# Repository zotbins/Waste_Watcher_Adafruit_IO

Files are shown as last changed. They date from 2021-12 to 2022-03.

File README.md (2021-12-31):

# Waste Watcher Adafruit IO
<!-- ALL-CONTRIBUTORS-BADGE:START - Do not remove or modify this section -->

<!-- ALL-CONTRIBUTORS-BADGE:END -->

Waste Watcher is an IoT based sensor module to help keep track of waste data metrics with real-time bin fullness data and waste images. This is intended to help quantify and promote actionable solutions to reduce waste. This project is a continuation of [waste_watcher](https://github.com/zotbins/waste_watcher).

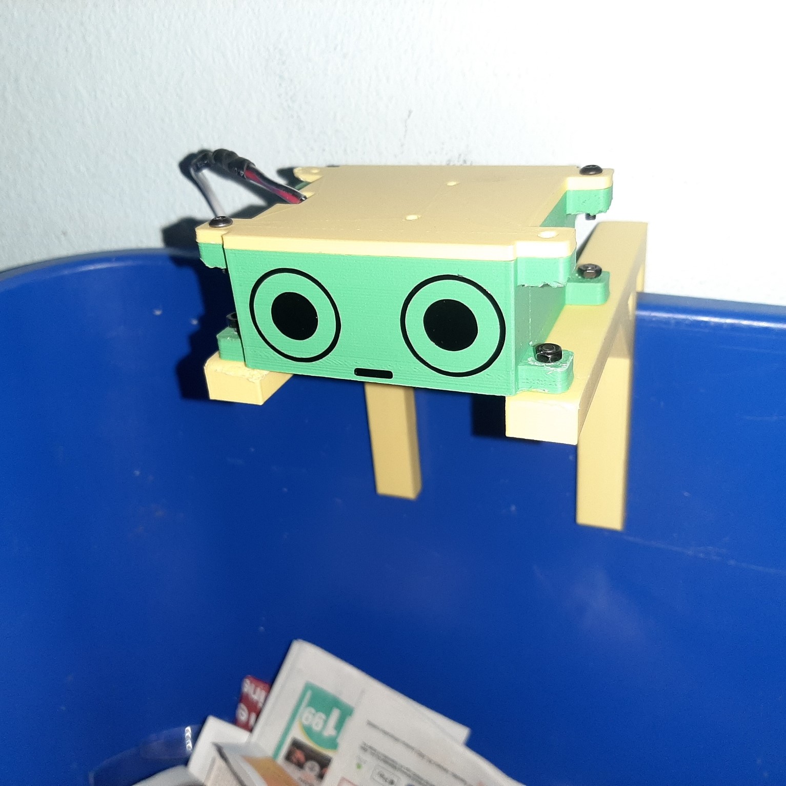
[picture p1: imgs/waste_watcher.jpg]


## Features

- 🗑 Collect waste bin fullness telemetry
- 📷 Capture image of inside the waste bin
- 🔧 Fully customizable (adjust data collection rate, tweak case design for your needs, change camera settings, etc.)

## Why?  ¯\\_(ツ)_/¯
Simply put, we generate way too much waste here in the United States 🤧. According to the [EPA](https://www.epa.gov/sites/default/files/2019-03/documents/infographic_full-060513_v4.pdf), 267.8 million tons of trash were generated. And even though the US represents 4% of the global population we generate 12% of global municipal solid waste, right behind India and China ( [Verisk Maplecroft, 2019](https://www.maplecroft.com/insights/analysis/us-tops-list-of-countries-fuelling-the-mounting-waste-crisis/)). The trash itself also presents other harmful environmental impacts. US landfills are the 3rd largest source of human-related methane emissions ([EPA](https://www.epa.gov/lmop/basic-information-about-landfill-gas)). Waste also affects 43% of marine mammals ([EPA 2017](https://19january2017snapshot.epa.gov/trash-free-waters/impacts-mismanaged-trash_.html)).

Waste monitoring systems already exist in commercial settings, ZotBins expands waste monitoring to the individual and community level. Some of these existing systems include [Bigbelly](https://bigbelly.com/), [Compology](https://compology.com/), and [Enevo](https://enevo.com/index.html). ZotBins is completely opensource. Built for people, by people.

## Adafruit IO

This repo, in particular, uses [Adafruit IO](https://io.adafruit.com/), an off-the-shelf IoT platform. For now, Adafruit IO is a great addition to this project and helps in the following ways:
- 🤗 Helps makes the project more user-friendly (no need to setup your own server, ready to use APIs, Dashboard feature)
- 🆓 Free to use F O R E V E R ╰(*°▽°*)╯ (according to their [website](https://io.adafruit.com/))
- 🤝 Great community on Discord willing to help people out
- 🔒 Data is never [sold](https://www.adafruit.com/iotbor/)

## Getting Started

Follow the [Build Guide](./build_guide.md) 🛠.

## Actionable Ideas for Your Waste Data

Besides just collecting data, here are some ideas that you can implement. Again the goal of this project is to help quantify and promote actionable solutions to reduce waste.

- 🎯 Create a goal to reduce the rate at which you fill up a bin
- 💻 Use the Adafruit IO Integrations (Zapier, IFTTT)
    - Send a summary of weekly fullness rate
    - Send alerts when bin is full
- 🤖 Use machine learning to identify what items are thrown always
    - identify frequently thrown away items then try to reduce that waste (eg. plastic straws are identified frequently in the waste stream, so we can ban the straw or give sustainable alternatives)
    - identify which waste items are incorrectly thrown away

## Contributors ✨

Thanks goes to these wonderful people ([emoji key](https://allcontributors.org/docs/en/emoji-key)):
<!-- ALL-CONTRIBUTORS-LIST:START - Do not remove or modify this section -->
<!-- prettier-ignore-start -->
<!-- markdownlint-disable -->
<table>
  <tr>
    <td align="center"><a href="http://www.ics.uci.edu/~primal/"><br /><sub><b>Primal Pappachan</b></sub></a><br /><a href="https://github.com/zotbins/Waste_Watcher_Adafruit_IO/pulls?q=is%3Apr+reviewed-by%3Aprimalpop" title="Reviewed Pull Requests">👀</a></td>
    <td align="center"><a href="https://github.com/patrickanguyen"><br /><sub><b>Patrick Nguyen</b></sub></a><br /><a href="https://github.com/zotbins/Waste_Watcher_Adafruit_IO/commits?author=patrickanguyen" title="Code">💻</a> <a href="https://github.com/zotbins/Waste_Watcher_Adafruit_IO/pulls?q=is%3Apr+reviewed-by%3Apatrickanguyen" title="Reviewed Pull Requests">👀</a></td>
  </tr>
</table>

<!-- markdownlint-restore -->
<!-- prettier-ignore-end -->

This project follows the [all-contributors](https://github.com/all-contributors/all-contributors) specification. Contributions of any kind welcome!

## Credits/Acknowledgements

1. [ESP32Cam-MQTT by abish7643](https://github.com/abish7643/ESP32Cam-MQTT) - Great reference in how to send images through MQTT
2. [ESP32-CAM Projects by Random Nerd Tutorials](https://randomnerdtutorials.com/projects-esp32-cam/) - Quality background information on getting started with the ESP32-CAM

## How this Project Started

This project started at UCI in 2017 with a group of 4 undergraduates for a hackathon hosted by UCI TIPPERS. The aim of the project was to help create a tool to help with UCI's zero waste initiatives. Since then, the project is being shared to the open-source community through ZBCE and the ZotBins UCI undergraduate team continues with new members every year.

## Other Links

1. [License](LICENSE)
2. [Contributing](CONTRIBUTING.md)
3. [Code of Conduct](CODE_OF_CONDUCT.md)

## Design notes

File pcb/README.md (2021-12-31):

## Waste Watcher PCB

The original KiCad project files are included so that you can modify it. Extract the project files from the `.zip` file and view it with [KiCad](https://www.kicad.org/).

You can also purchase the PCB from [OshPark](https://oshpark.com/) using this [link](https://oshpark.com/shared_projects/9fNFnSUL).

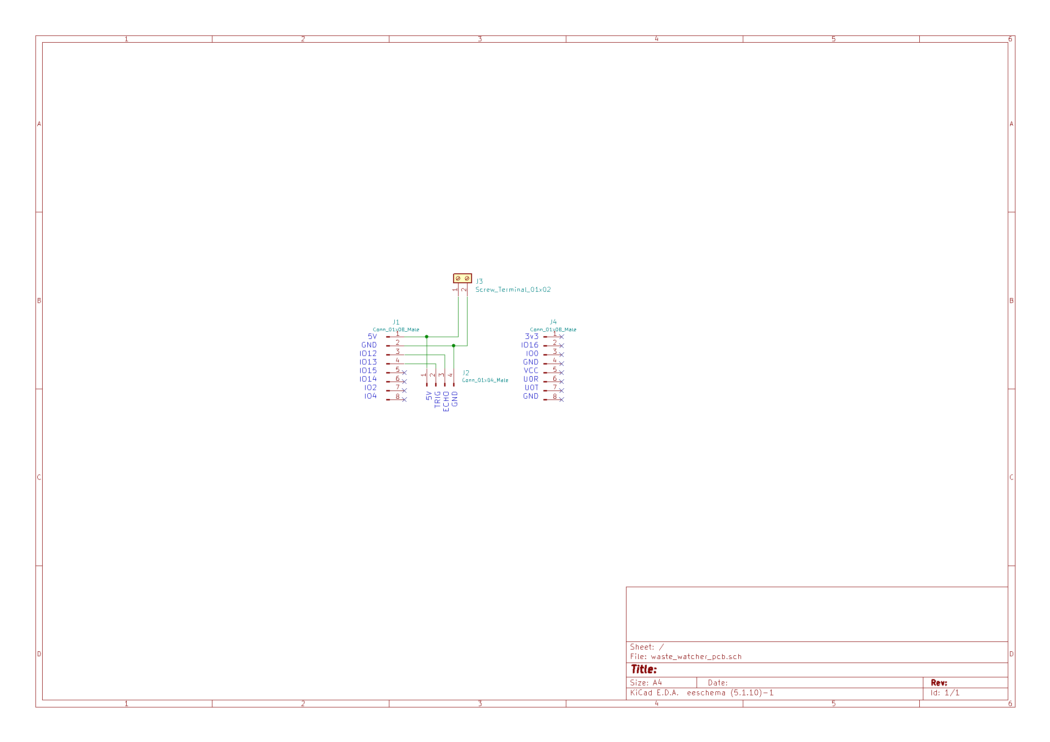
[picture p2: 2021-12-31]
pcb/schematic.png

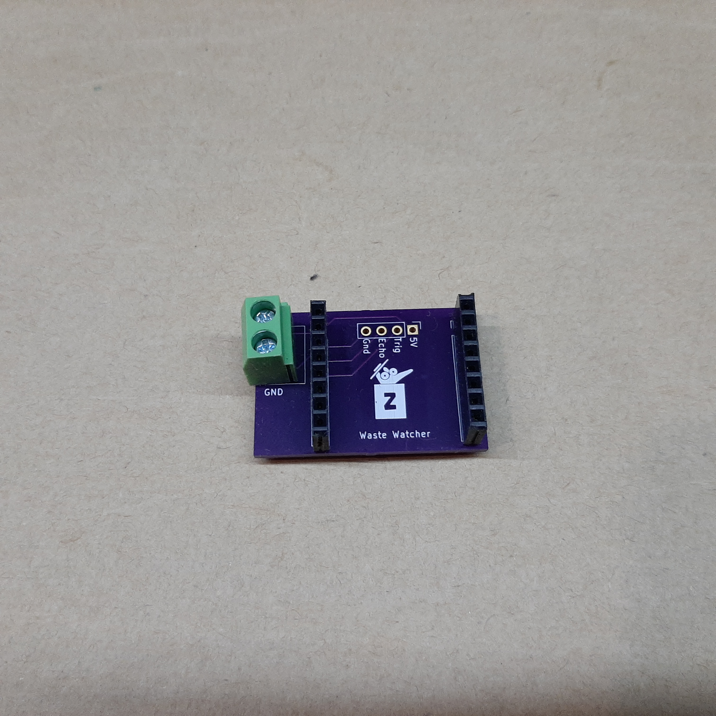
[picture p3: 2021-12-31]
imgs/zotbins_pcb.jpg

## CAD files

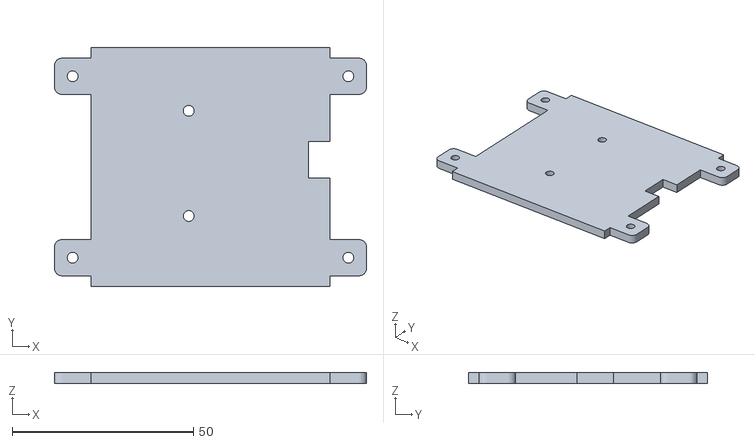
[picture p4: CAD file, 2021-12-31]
stl/sensor_mod_top_assembly.stl
86.0 x 66.0 x 3.00

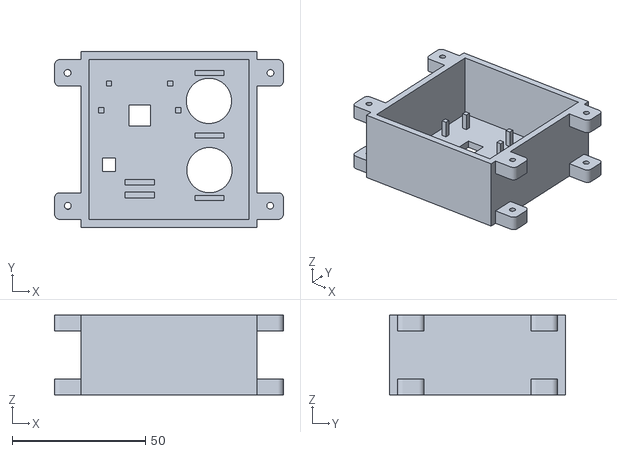
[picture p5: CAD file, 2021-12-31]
stl/sensor_mod_bottom_assembly.stl
86.0 x 66.0 x 30.0

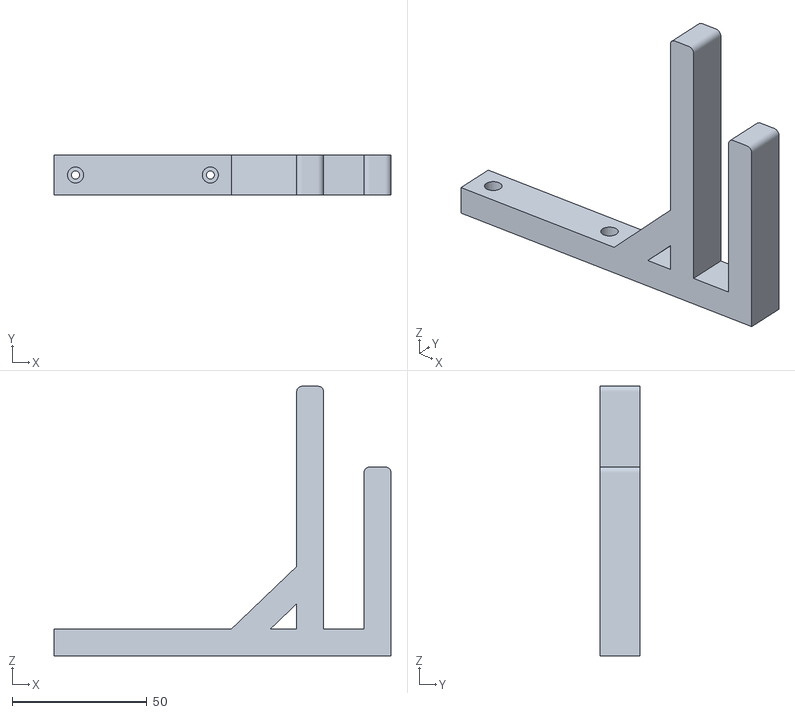
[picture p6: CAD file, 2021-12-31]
stl/sensor_mod_handle.stl
125.0 x 15.0 x 100.0

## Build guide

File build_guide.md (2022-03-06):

# Waste Watcher Build Guide

The intent of this guide is to be clear and provide comprehensive instruction to help you build and setup your waste watcher. If you would like to suggest any improvements feel free to submit an issue or refer to the [Contributing](CONTRIBUTING.md) Guide.

## Materials
- [ ] PLA Filament
- [ ] ESP32-CAM
- [ ] HC-SR04
- [ ] Solid Core Wire
- [ ] Waste Watcher PCB
- [ ] 6 of 12mm M3 Screws
- [ ] 6 M3 nuts
- [ ] 1 of the 2 Pin Screw Terminal
- [ ] 2 of the 1 x 8 Female header pins
- [ ] Spare USB cable
- [ ] Heat Shrink

## Equipment Needed
- [ ] 3D printer (or 3D Printing Service)
- [ ] Soldering Iron
- [ ] Helpings Hands for Soldering
- [ ] Wire Stripper
- [ ] Computer
- [ ] FTDI Adapter and 4 Female to Female Adapter
- [ ] Jumper Cap

## 1 - 3D Print the Case
If you don't have a 3D printer, you can search up some local 3D printing services in your favorite search browser.

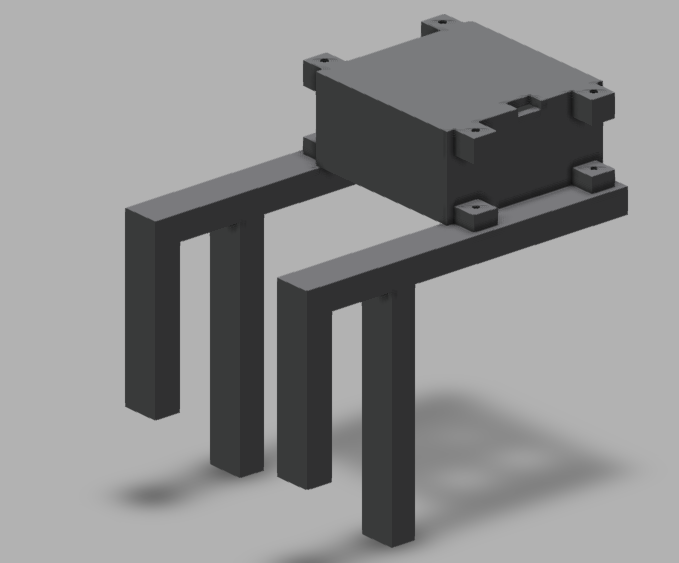
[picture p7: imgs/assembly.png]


1. Before starting make sure that your bin is compatible with the case. If not, you may need to modify or create different handles. (please share them if you do! 🙂)
2. Refer to the settings below and print the following:
    1. 2 of the `sensor_mod_handle.stl`
    2. 1 of the `sensor_mod_bottom_assembly.stl`
    3. 1 of the `sensor_mod_top_assembly.stl`
3. Screw on the handles
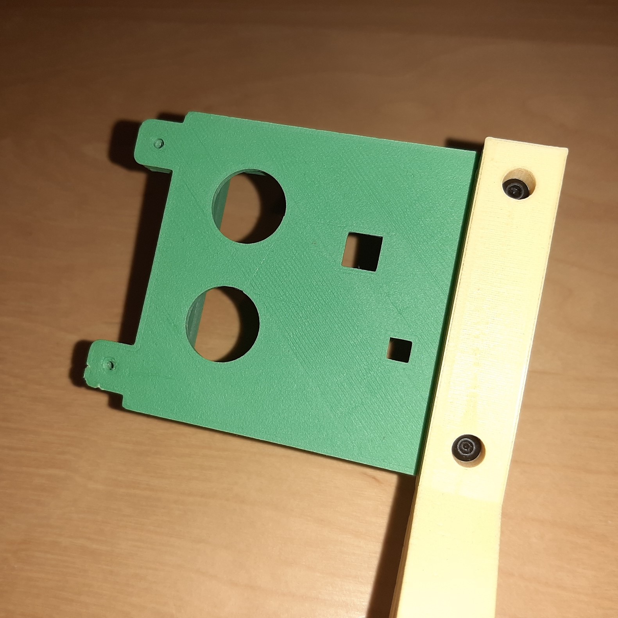
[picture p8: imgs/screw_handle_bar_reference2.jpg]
    

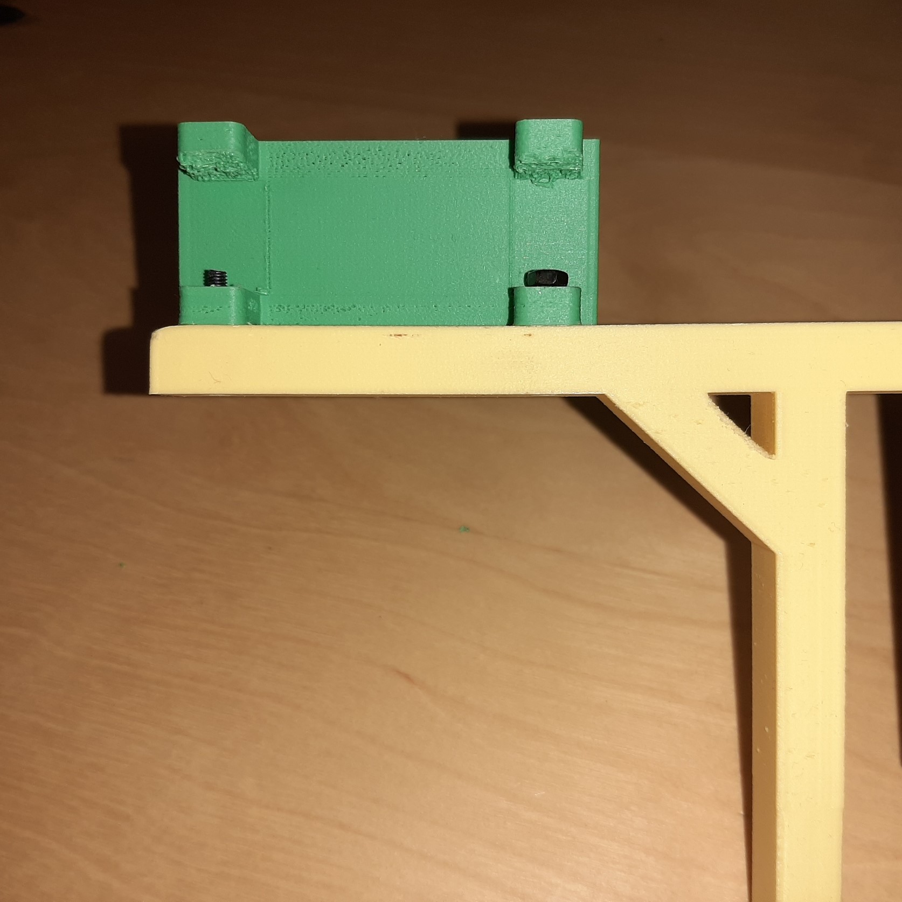
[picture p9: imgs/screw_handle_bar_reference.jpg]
    

| Setting | Value |
| ---| ----- |
| Layer height (mm) | 0.1 |
| Shell thickness (mm) | 0.8 |
| Bottom/Top thickness (mm) | 1.5 |
| Fill Density (%) | 30 |
| Print speed (mm/s) | 50 |
| Support type | Everywhere |
| Platform adhesion type | None |

## 2 - Circuit
You can purchase the PCB from [OshPark](https://oshpark.com/) using this [link](https://oshpark.com/shared_projects/9fNFnSUL). Or if you prefer, you can refer to the schematic/KiCad files in the `pcb` folder and create your circuit on a prototyping board.

1. Let's recycle! ♻ Take your spare USB cable, cut the end, and expose the V+ (usually red) and GND (usually black)
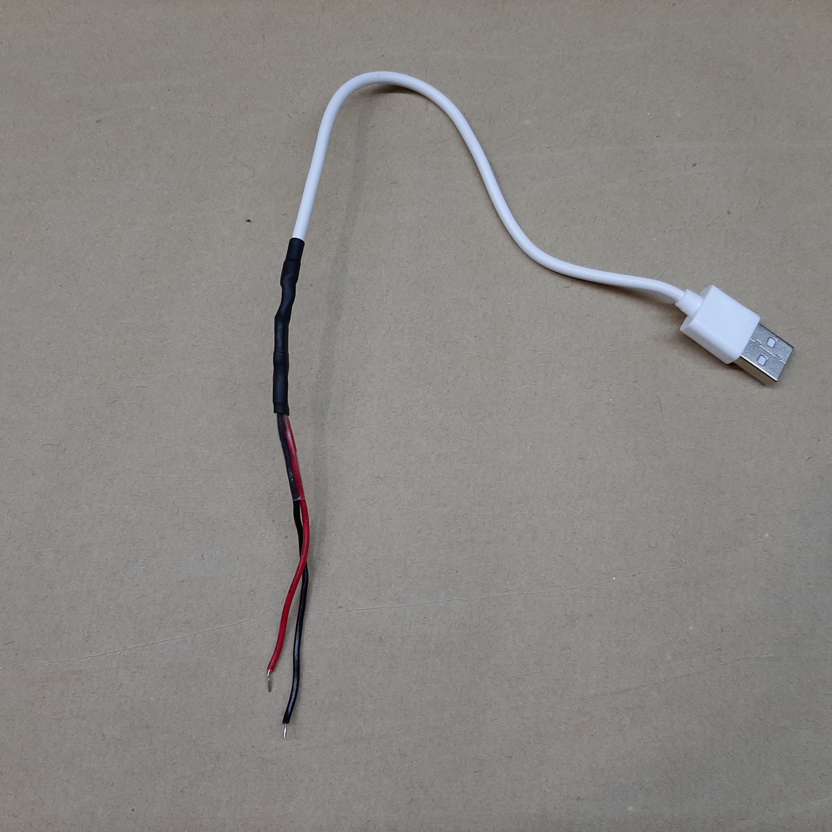
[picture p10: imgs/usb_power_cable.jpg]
    
2. Solder the components onto the PCB
    1. 2 Pin Screw Terminal
    2. 2 of the 1 x 8 Female header pins
3. Solder some wires onto the HC-SR04
4. Heat shrink to insulate
5. Solder the other ends of the wires into the PCB (use the labels to figure out which wire goes where)
3. Your circuit is good to go 👍
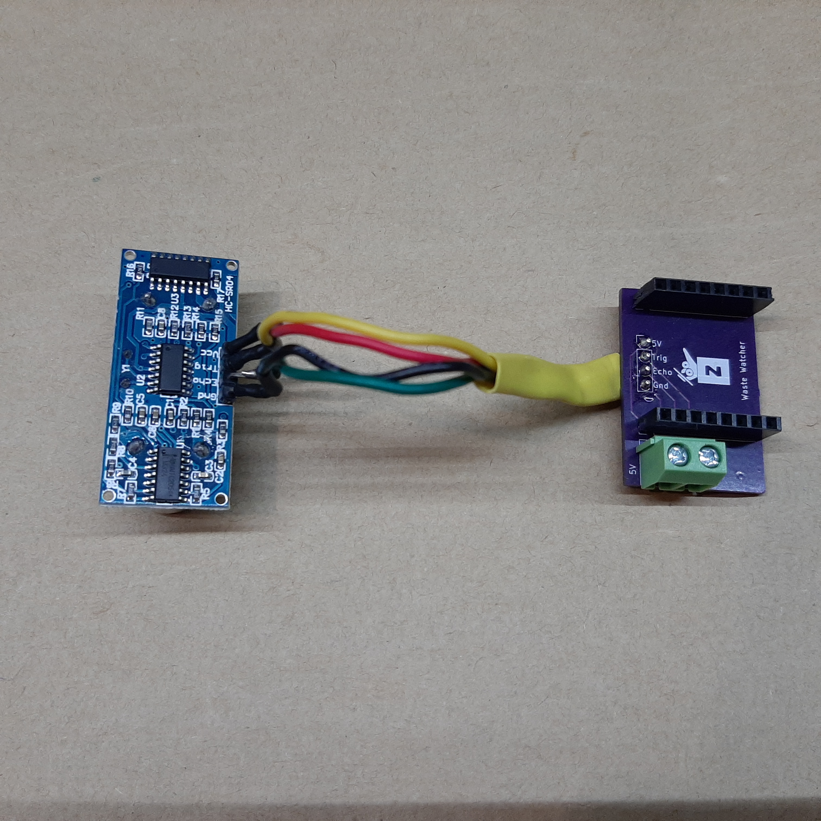
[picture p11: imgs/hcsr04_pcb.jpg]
    

## 3 - Adafruit IO Setup
1. Create an Adafruit IO account
2. Take note of your Adafruit IO Username and Key
    

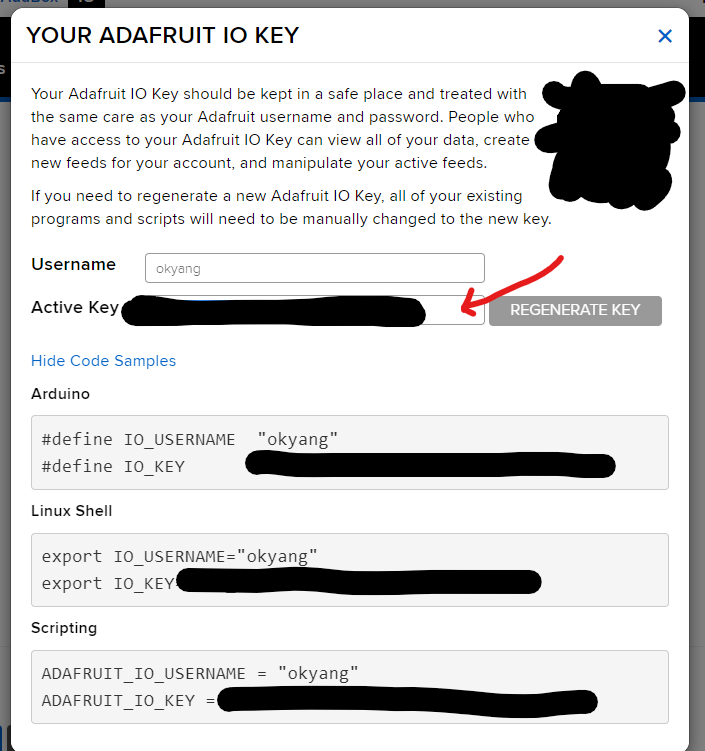
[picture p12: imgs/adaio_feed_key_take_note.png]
    
3. Create a Group
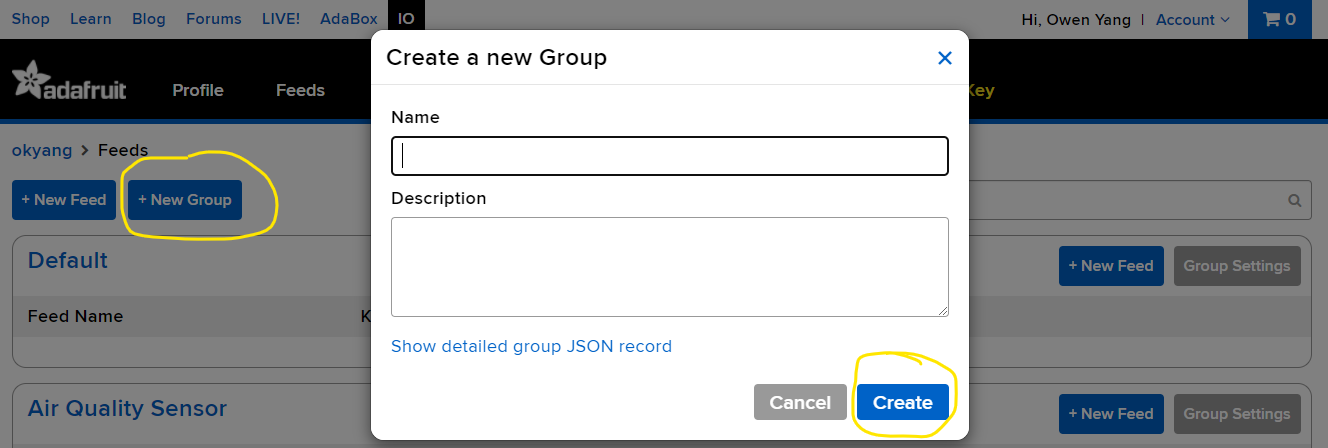
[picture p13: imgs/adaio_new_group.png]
    
4. Create your feeds for
    1. Bin Fullness
    2. Waste Image
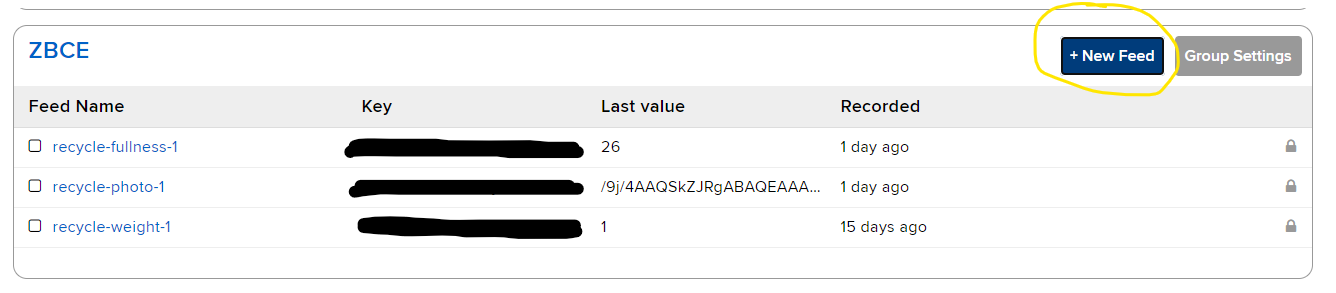
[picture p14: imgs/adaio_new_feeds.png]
    
5. Create a [Dashboard](https://learn.adafruit.com/adafruit-io-basics-dashboards) for your feeds. Here's an example that I made.
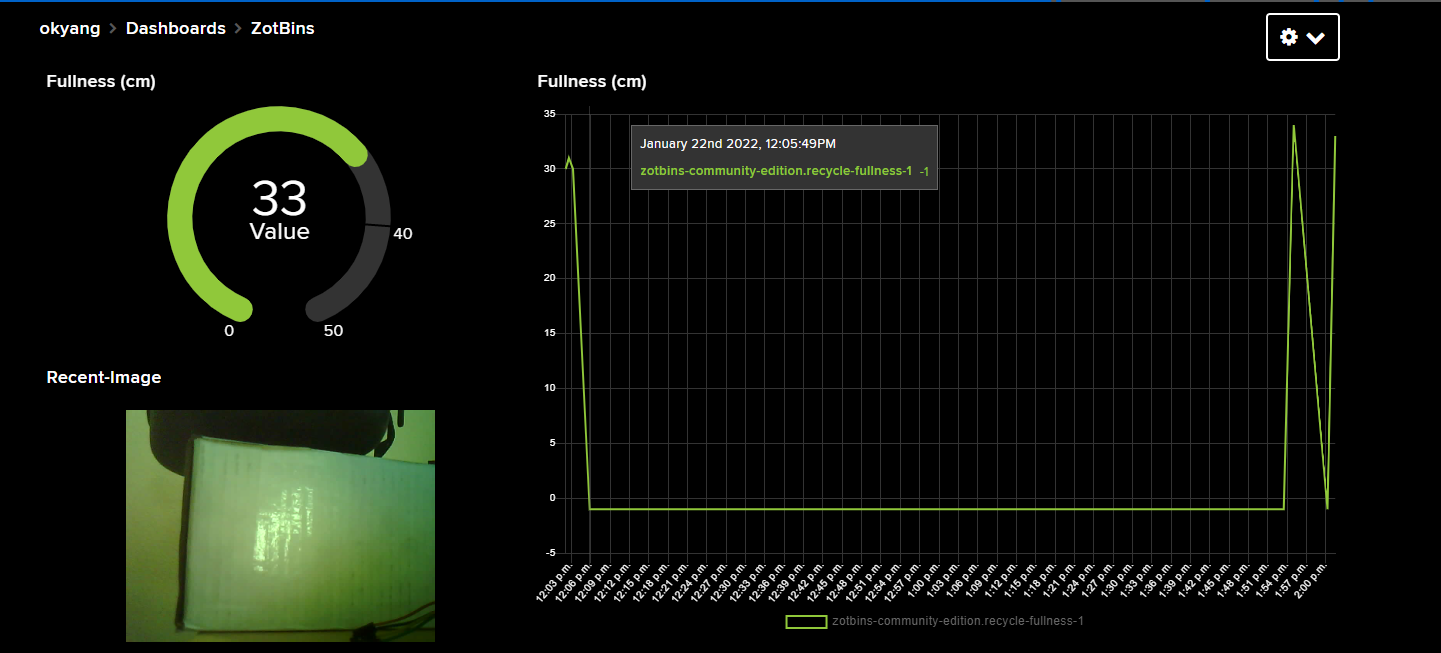
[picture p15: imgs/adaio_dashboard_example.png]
    

## 4 - Upload Code
Before getting started, make sure you satisfy these prerequisites below:
- [Visual Studio Code](https://code.visualstudio.com/)
- [Platform IO Extension Installed](https://platformio.org/install/ide?install=vscode)
- Repo Code Downloaded:
    - (Option 1) Download repo as zip and extract the contents
    - (Option 2) `git clone https://github.com/zotbins/Waste_Watcher_Adafruit_IO.git`

1. Open the subfolder `waste_watcher_adafruitIO` in Visual Studio Code
2. Create the file `config.h` in the `src` folder
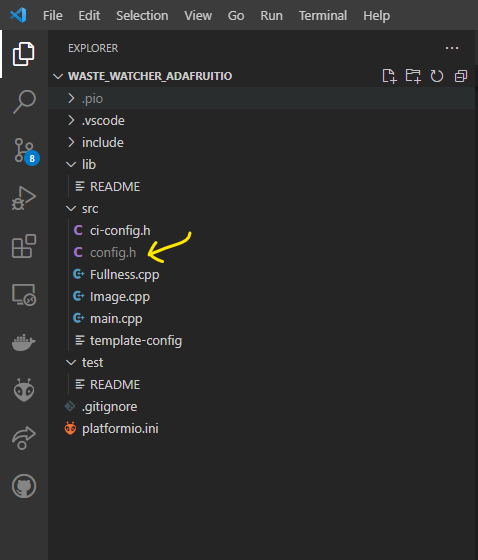
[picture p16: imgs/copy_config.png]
    
3. Copy the contents of `template-config` into your `config.h` file
4. Change the config settings for the following
    - `ssid` - your wifi name
    - `password` - this is your wifi password
    - `mqttClientID` - just a unique id. You can generate one with https://guidgenerator.com/
    - `mqttUsername` - this is your AdafruitIO username
    - `mqttPassword` - this your AdafruitIO key in the form of `<username>/feeds/<MQTT by Key>`. The key! Not your account password.
    - `mqttFullnessTopic` - the MQTT topic for the fullness feed you created
    - `mqttImageTopic` - the MQTT topic for the image feed you created
5. Measure the height of your bin and change `binHeight` value to reflect the height of your particular bin. That way the sensor module can calculate how full your bin is.
6. Change the other config settings as you see fit
7. Put a jumper cap on the ESP32-CAM `IO0` and `GND`
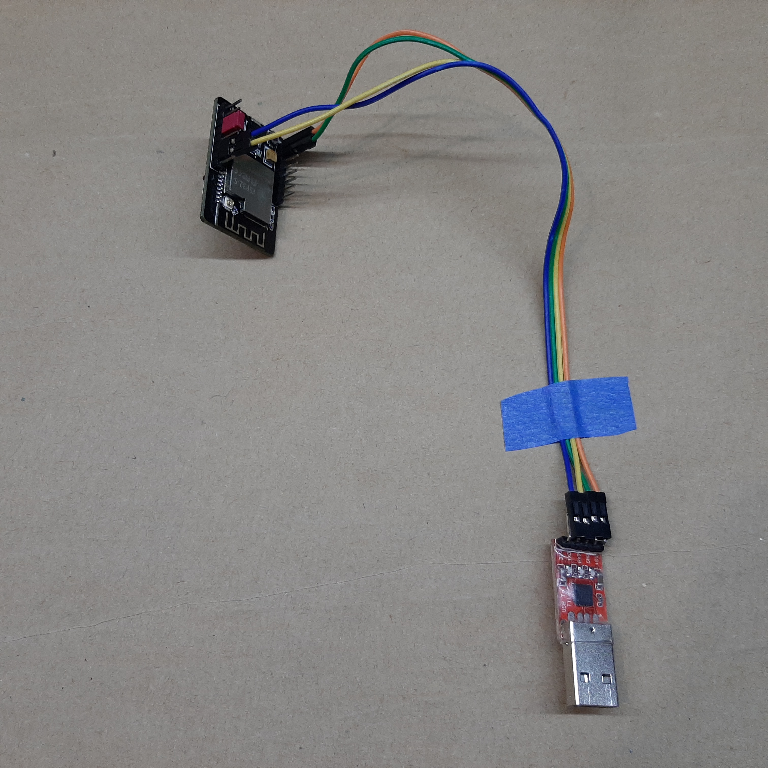
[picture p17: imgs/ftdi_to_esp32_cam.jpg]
    
8. Plug in your FTDI Adapter to the ESP32-CAM as shown
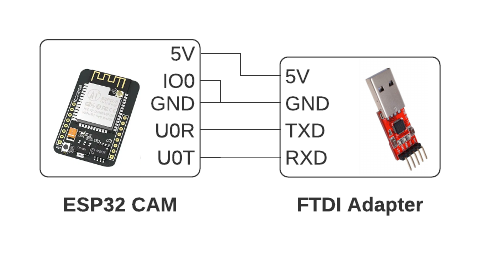
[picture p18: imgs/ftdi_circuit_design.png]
    
9. Plug in the FTDI Adapter into your computer
10. Click on the PlatformIO icon on the left side panel, then click **Upload and Monitor**. Wait for this to finish.
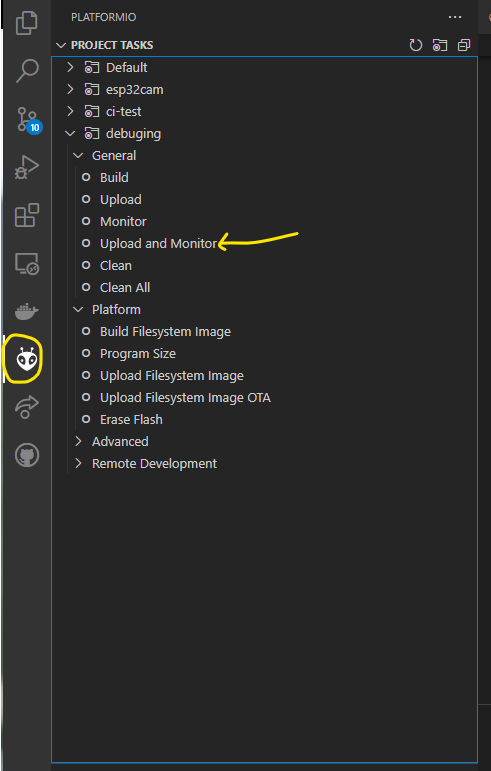
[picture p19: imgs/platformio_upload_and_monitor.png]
    
12. While leaving the ESP32-CAM plugged into the computer, Unplug the Jumper Cap and hit the reset button
13. Wait for data to be sent in Adafruit IO
    1. Fullness data should be sent as `-1` (because there is no HC-SR04 connected yet)
    2. Image should be sent

For troubleshooting the ESP32-CAM checkout this guide: [ESP32-CAM Troubleshooting Guide](https://randomnerdtutorials.com/esp32-cam-troubleshooting-guide/)

## 5 - Monitor Waste and Create Actionable Solutions

1. Plug your ESP32-CAM into your PCB
2. Screw in the USB power wires as shown (do not mix up power and ground!)
3. Put the HC-SR04 in and then the ESP32CAM in.
3. Screw on the lid with the USB cable coming out of the rectangular hole on top



Here are some actionable ideas from the README file:
> Besides just collecting data, here are some ideas that you can implement. Again the goal of this project is to help quantify and promote actionable solutions to reduce waste.
>
> - 🎯 Create a goal to reduce the rate at which you fill up a bin
> - 💻 Use the Adafruit IO Integrations (Zapier, IFTTT)
>    - Send a summary of weekly fullness rate
>    - Send alerts when bin is full
> - 🤖 Use machine learning to identify what items are thrown always
>    - identify frequently thrown away items then try to reduce that waste (eg. plastic straws are identified frequently in the waste stream, so we can ban the straw or give sustainable alternatives)
>    - identify which waste items are incorrectly thrown away

## Resources/Links
1. [Getting Started with VS Code and PlatformIO IDE for ESP32 and ESP8266 (Windows, Mac OS X, Linux Ubuntu)](https://randomnerdtutorials.com/vs-code-platformio-ide-esp32-esp8266-arduino/) - A guide to install Visual Studio Code and the PlatformIO Extension by Random Nerd Tutorials
2. [ESP32-CAM Video Streaming and Face Recognition with Arduino IDE](https://randomnerdtutorials.com/esp32-cam-video-streaming-face-recognition-arduino-ide/) - Great introduction to the ESP32-CAM by Random Nerd Tutorials
3. [ESP32-CAM Troubleshooting Guide](https://randomnerdtutorials.com/esp32-cam-troubleshooting-guide/) - common problems fixed for the ESP32-CAM by Random Nerd Tutorials

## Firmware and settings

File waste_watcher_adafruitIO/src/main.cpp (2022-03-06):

#include <Arduino.h>

#include "soc/soc.h"           // Disable brownout problems
#include "soc/rtc_cntl_reg.h"  // Disable brownout problems

#include <WiFi.h>
#include <PubSubClient.h>

#include <base64.h>
#include "Fullness.h"
#include "Image.h"

// create a `config.h` file based off of `template-config.h`
#ifdef CI
#include "ci-config.h"
#else
#include "config.h"
#endif

WiFiClient espClient;
PubSubClient client(espClient);

void reconnect();
void setup_wifi();

void setup_wifi()
{
  delay(10);
  // We start by connecting to a WiFi network
  #ifndef NDEBUG
  Serial.println();
  Serial.print("Connecting to ");
  Serial.println(ssid);
  #endif

  WiFi.begin(ssid, password);

  while (WiFi.status() != WL_CONNECTED)
  {
    delay(500);

    #ifndef NDEBUG
    Serial.print(".");
    #endif
  }

  #ifndef NDEBUG
  Serial.println("");
  Serial.println("WiFi connected");
  Serial.println("IP address: ");
  Serial.println(WiFi.localIP());
  #endif
}

void reconnect() {
  // Loop until we're reconnected
  while (!client.connected())
  {
    #ifndef NDEBUG
    Serial.print("Attempting MQTT connection...");
    #endif

    // Attempt to connect
    if (client.connect(mqttClientID, mqttUsername, mqttPassword))
    {
      #ifndef NDEBUG
      Serial.println("connected");
      #endif
    }
    else
    {
      #ifndef NDEBUG
      Serial.print("failed, rc=");
      Serial.print(client.state());
      Serial.println(" try again in 5 seconds");
      #endif

      // Wait 5 seconds before retrying
      delay(5000);
    }
  }
}

void setup() {
  #ifndef NDEBUG
  Serial.begin(115200);
  #endif

  // === deep sleep setup ===
  esp_sleep_enable_timer_wakeup(TIME_TO_SLEEP * uS_TO_S_FACTOR);

  // ---- set pins -----
  pinMode(ultrasonicTrigPin, OUTPUT);
  pinMode(ultrasonicEchoPin, INPUT);
  pinMode(FLASH, OUTPUT);

  // ---- telemetry variables ----
  int fullness;
  String base64Image; //base-64 encoded string to represent a JPG image

  // ---- Read Fullness ----
  fullness = calculateFullness(ultrasonicTrigPin, ultrasonicEchoPin, binHeight, 0, binHeight, retries);

  // ---- Get Picture ----
  configInitCamera();
  base64Image = takePhoto(flashOn);

  #ifndef NDEBUG
  Serial.print("\nFullness: ");
  Serial.println(fullness);
  Serial.println("Image captured.");
  if (base64Image.length() > 102400) {
    Serial.println("Image size too big");
    return;
  }
  #endif

  // ---- MQTT Setup -----
  setup_wifi();
  client.setServer(mqttServer, 1883);
  if (!client.connected()) {
    reconnect();
  }
  client.loop();

  // ----- Send Fullness Telemetry w/ 5 retry chances-----
  char payload[32] = {0};
  snprintf(payload, sizeof(payload), "%d", fullness);

  bool fullnessSent;
  for (int i=0; i<5; i++) {
    fullnessSent = client.publish(mqttFullnessTopic, payload);
    if (fullnessSent) break;
    delay(1000);
  }

  // --- Send Picture to MQTT w/ 5 retry chances ---
  bool imageSent;
  for (int i=0; i<6; i++) {
    imageSent = client.publish(mqttImageTopic, base64Image.c_str());
    if (imageSent) break;
    delay(1000);
  }

  // ---- deep sleep ----
  #ifndef NDEBUG
  if (fullnessSent) Serial.println("Fullness Telemetry Sent");
  if (imageSent) Serial.println("Image Telemetry Sent");

  Serial.println("Going to sleep now");
  delay(1000);
  Serial.flush();
  #endif

  esp_deep_sleep_start();
}

void loop() {

}

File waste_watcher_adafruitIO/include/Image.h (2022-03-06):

#ifndef IMAGE_H
#define IMAGE_H

#include <Arduino.h>

//CAMERA_MODEL_AI_THINKER
#define FLASH              4
#define PWDN_GPIO_NUM     32
#define RESET_GPIO_NUM    -1
#define XCLK_GPIO_NUM      0
#define SIOD_GPIO_NUM     26
#define SIOC_GPIO_NUM     27

#define Y9_GPIO_NUM       35
#define Y8_GPIO_NUM       34
#define Y7_GPIO_NUM       39
#define Y6_GPIO_NUM       36
#define Y5_GPIO_NUM       21
#define Y4_GPIO_NUM       19
#define Y3_GPIO_NUM       18
#define Y2_GPIO_NUM        5
#define VSYNC_GPIO_NUM    25
#define HREF_GPIO_NUM     23
#define PCLK_GPIO_NUM     22

void configInitCamera();
String takePhoto(bool flashOn);

#endif
